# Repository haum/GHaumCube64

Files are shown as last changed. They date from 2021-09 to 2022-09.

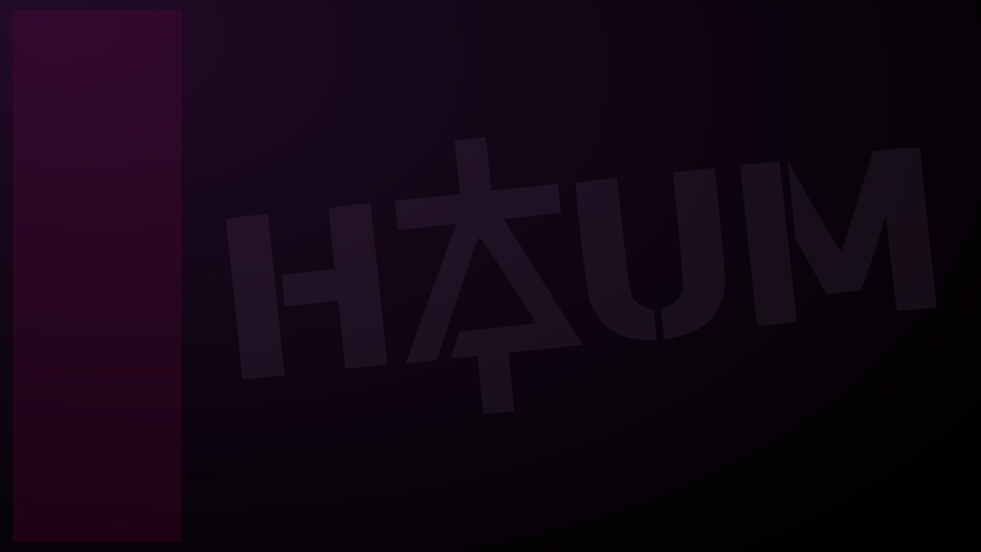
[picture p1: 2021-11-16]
code/screen_spy/bg.png

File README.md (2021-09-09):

# GHaumCube64

Le GHaumCube64 est un jeu lumineux tridimentionnel sous forme de cube suspendu dans les airs.

État du projet : En cours

## Description générale

À l'heure actuelle, le projet est définit comme étant un cube de 64 (4×4×4) tåls (nom inventé pour désigner les éléments lumineux, munis chacun de trois leds multicolores adressables), orienté sur sa pointe et suspendu ; il y a aussi une manette de jeu à lui adjoindre. L'objectif est d'y programmer des jeux tels que morpion/snake/tron en 3D.

## Organisation des fichiers

```
<repo>
├── code
│   ├── cube <= Code du cube
│   └── remote <= Code de la télécommande/manette de jeu
│   └── Tal_test <= Code de test des LEDs
└── structure
    ├── placement
    │   ├── cube.blend <= disposition des tåls dans l'espace
    │   └── placement.scad <= disposition des tåls dans l'espace, d'un point de vue fabrication
    └── tal
        ├── tal.blend <= Modèle d'un tål complet
        ├── tal_bottom.stl.xz <= Export STL (compressé) de la partie basse
        ├── tal_top.stl.xz <= Export STL (compressé) de la partie haute
        └── Ball
            ├── support_led_Tal.FCStd <= Support LEDs FreeCAD file
            └── support_led_Tal.stl <= Export STL du support de LEDs
```

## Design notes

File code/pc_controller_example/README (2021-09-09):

A few lines of Python to test tal flower LEDs

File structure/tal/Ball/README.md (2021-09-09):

As tal flowers are hard to print we starded a version with paper ball with LED inside.
Here is a support for LED inside choosen balls

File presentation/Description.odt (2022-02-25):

GHAUMCube64

Le GHAUMCube64 est une structure interactive, suspendue au dessus du sol qui propose 64 boules lumineuses multicolores disposées pour former un cube en 3D.

Il est augmenté de plusieurs télécommandes sans fil qui permettent d’interagir avec l'affichage et de prendre le contrôle du dispositif.

Avec cette installation le HAUM (Hackerspace AU Mans) emmènera les visiteurs dans un ballet de lumière à travers de jeux et de programmes spécialement développés pour que petits et grands puissent découvrir ce projets du HAUM de façon ludique, étonnante et amusante.

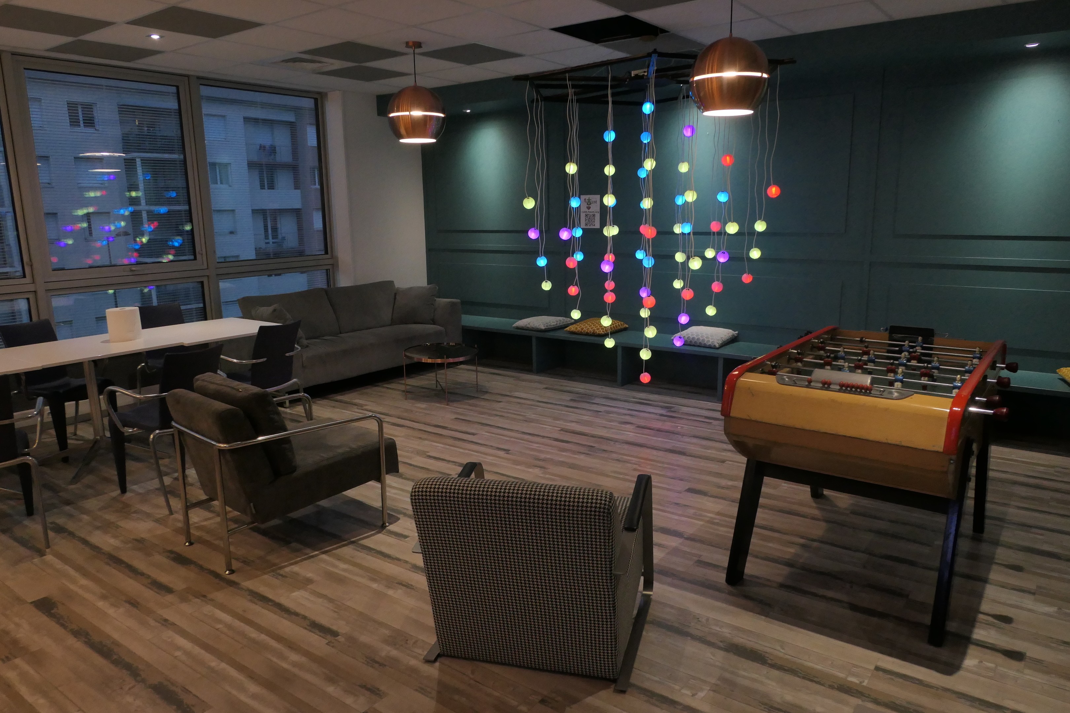
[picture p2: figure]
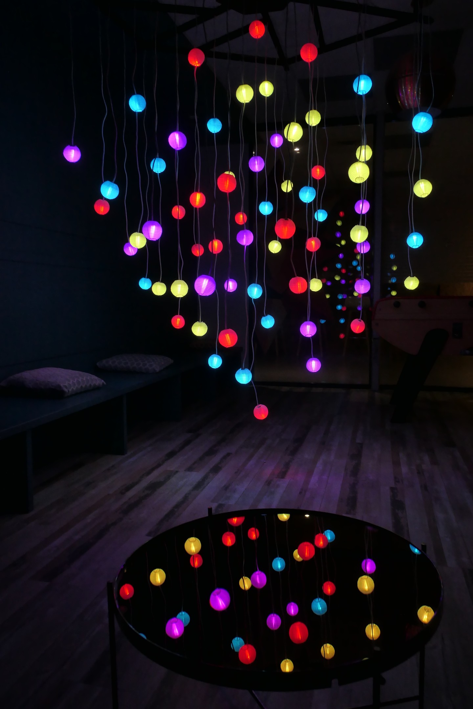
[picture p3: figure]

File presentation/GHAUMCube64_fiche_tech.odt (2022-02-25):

GHAUMCube64

Le GHAUMCube64 est une structure suspendue au-dessus du sol qui propose 64 boules lumineuses multicolores disposées pour former un cube en 3D.

Fiche technique :

installation : En intérieur

besoin électrique : Alimentation 16A qui arrive par le haut.

emprise au sol : Espace plat d’un minimum de 3m par 3m, si possible prévoir un espace libre devant pour que les spectateurs puissent appréhender la structure dans son ensemble.

Hauteur sous plafond : La structure peut être mise en œuvre dans une pièce avec une hauteur de plafond standard (2 m 60) grâce a son support autoportant. Pour une meilleure expérience il est préférable de pouvoir l’installer a une hauteur de 3m/3m50, soit grâce a son support, soit sur un point de fixation haut disponible dans la pièce l’accueillant.

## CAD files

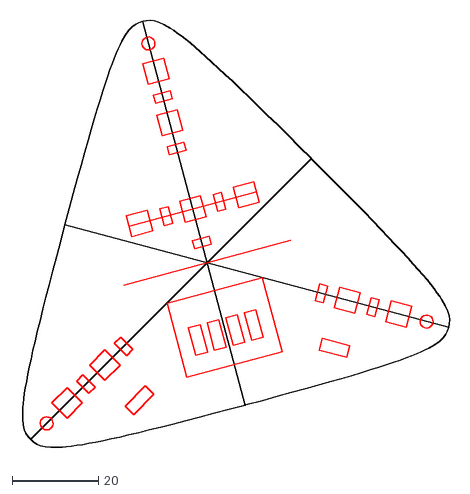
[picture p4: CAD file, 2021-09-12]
remote_board/kicad/outline_spots.dxf
101.5 x 101.5

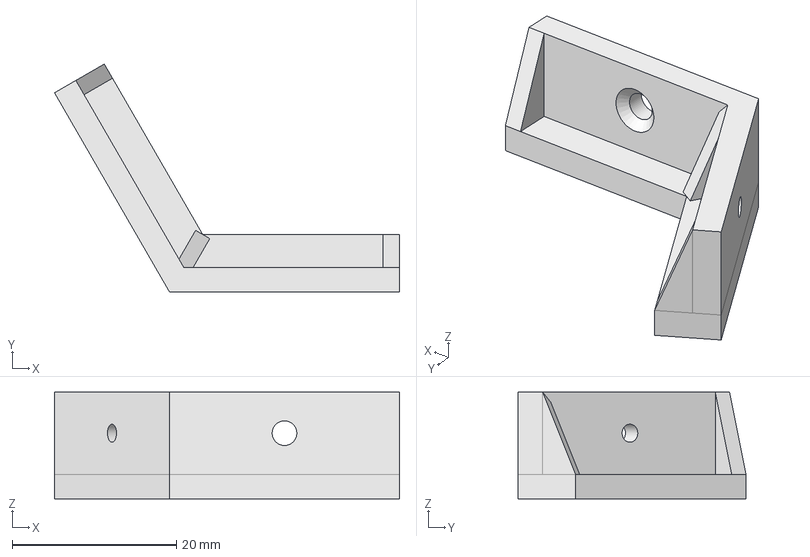
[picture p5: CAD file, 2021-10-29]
structure/placement/Doc_fabrication/connecteur_branches.FCStd
42.0 x 27.7 x 13.0 mm

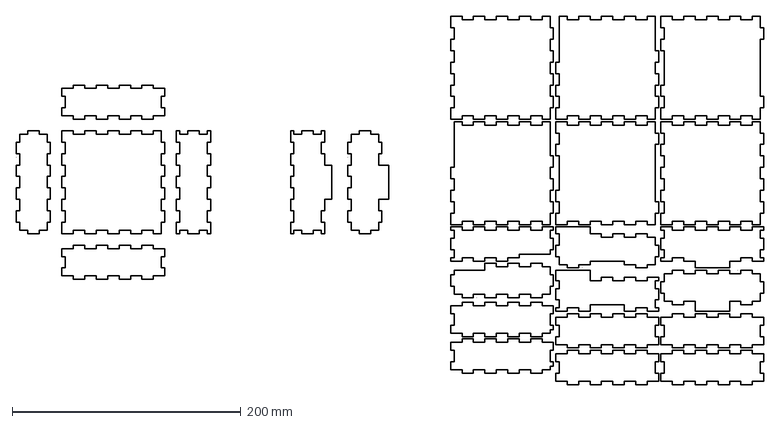
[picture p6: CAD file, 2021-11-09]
structure/placement/maquette_position_Tal.dxf
654.0 x 322.0 mm

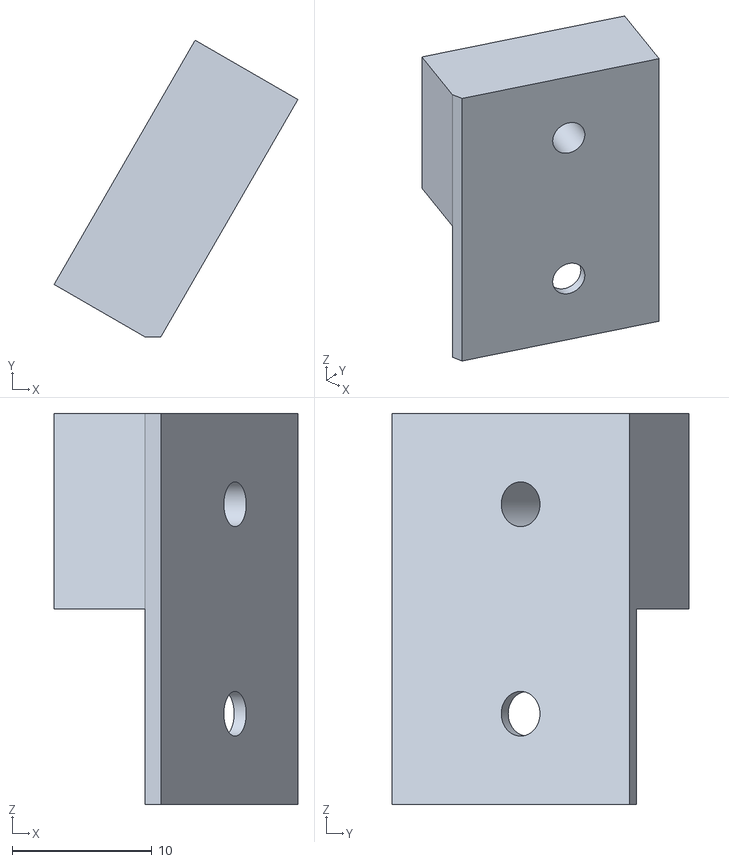
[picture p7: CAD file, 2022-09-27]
structure/raccord-support_charniere2.stl
17.5 x 21.2 x 28.0

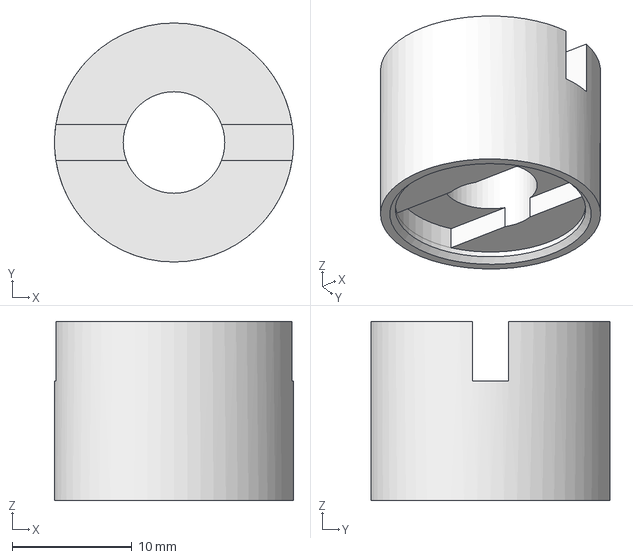
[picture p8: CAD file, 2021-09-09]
structure/tal/Ball/support_led_Tal.FCStd
20.0 x 20.0 x 15.0 mm

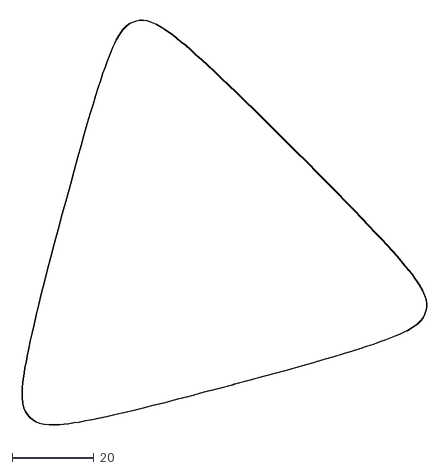
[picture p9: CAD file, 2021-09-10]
remote_board/kicad/outline.dxf
101.5 x 101.5

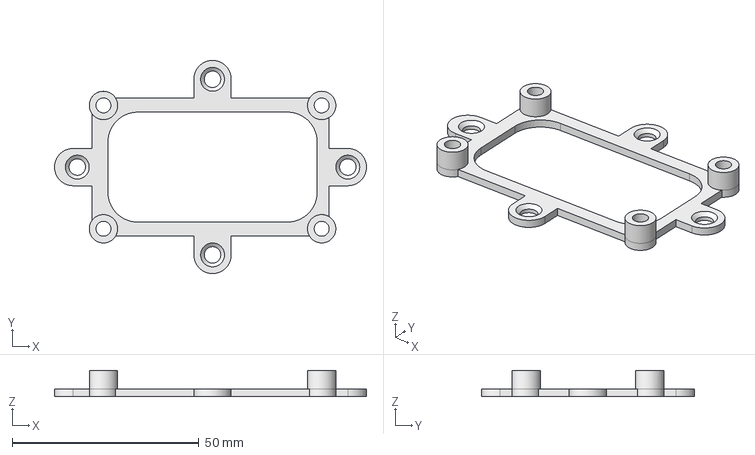
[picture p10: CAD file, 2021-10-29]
structure/placement/Doc_fabrication/support_Carte_ESP.FCStd
83.5 x 57.1 x 7.00 mm

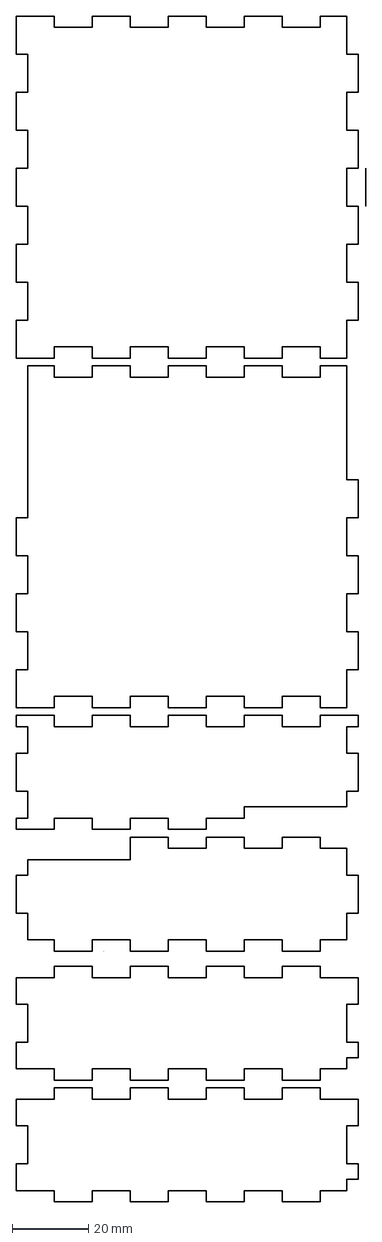
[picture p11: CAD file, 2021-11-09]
structure/placement/maquette_position_Tal1.dxf
92.0 x 312.0 mm

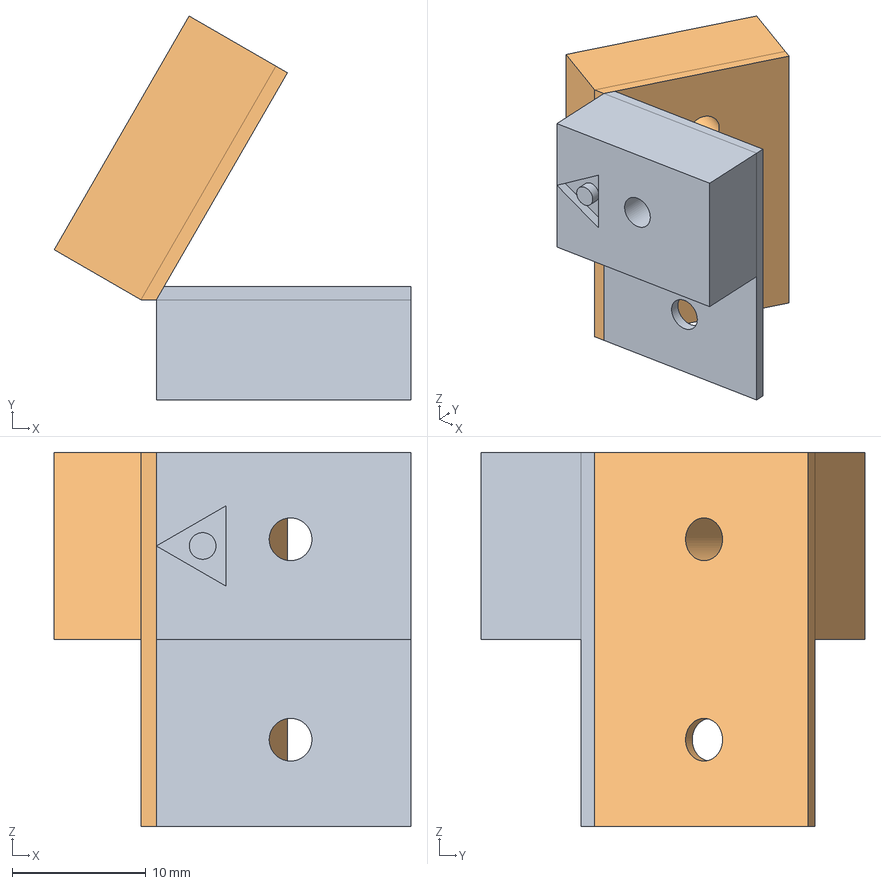
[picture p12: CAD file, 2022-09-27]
structure/raccord.FCStd
26.7 x 28.7 x 28.0 mm
support_charniere1
support_charniere2

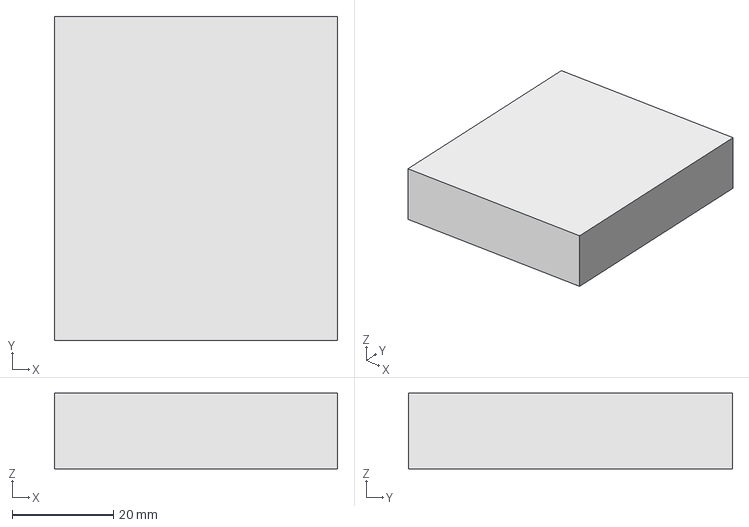
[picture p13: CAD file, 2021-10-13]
structure/placement/Doc_fabrication/centre.FCStd
56.0 x 64.0 x 15.0 mm

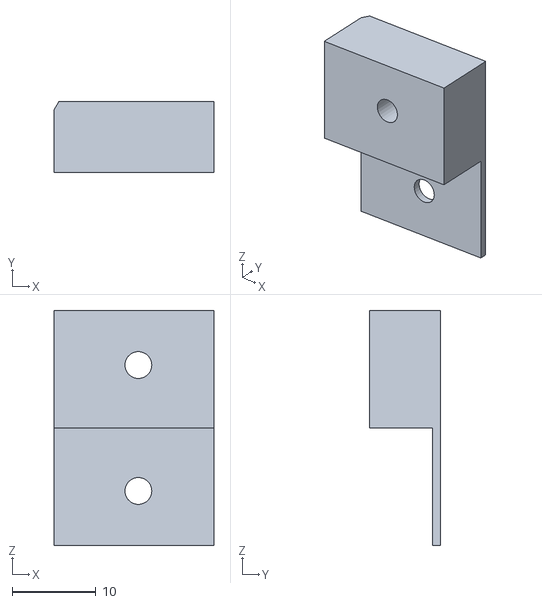
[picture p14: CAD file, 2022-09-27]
structure/raccord-support_charniere1.stl
19.0 x 8.50 x 28.0

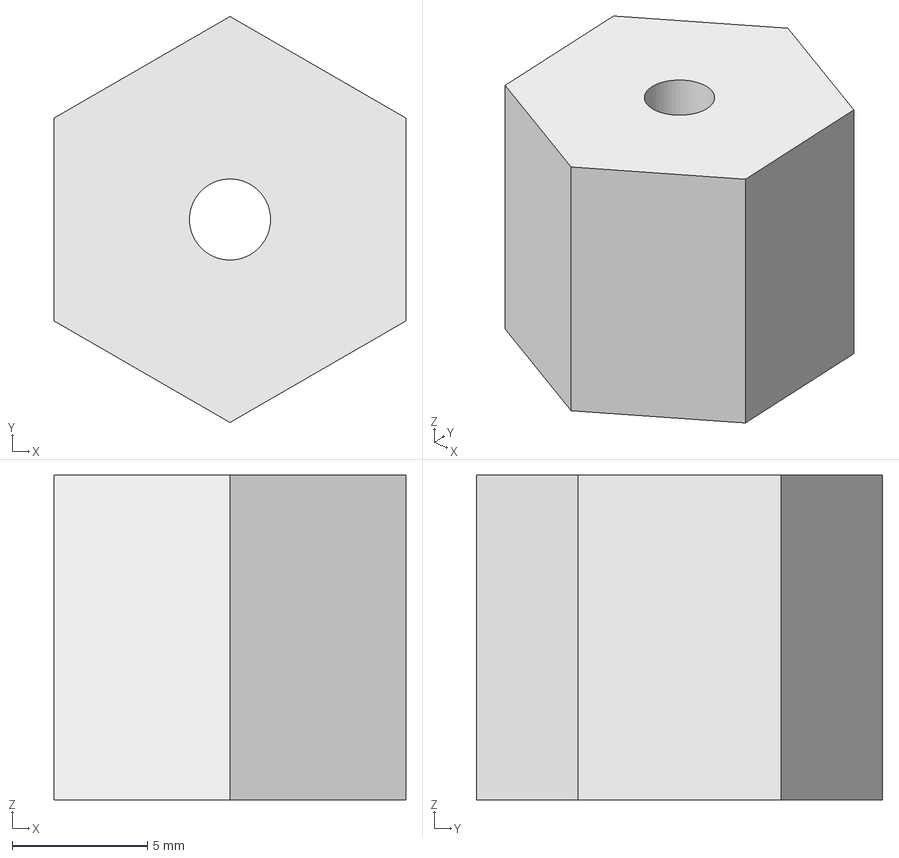
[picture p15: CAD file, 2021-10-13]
structure/placement/Doc_fabrication/Support_Alim.FCStd
13.0 x 15.0 x 12.0 mm

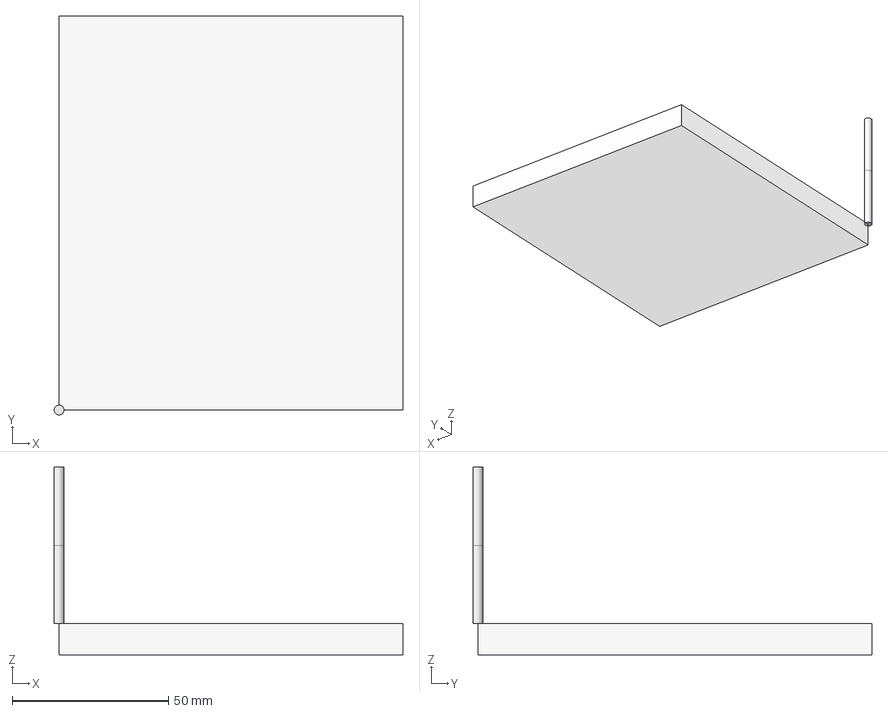
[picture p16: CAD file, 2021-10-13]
structure/placement/Doc_fabrication/support_central.FCStd
111.5 x 127.6 x 60.0 mm
Model-Body
Stock
2mm_wood
3_17mm-std

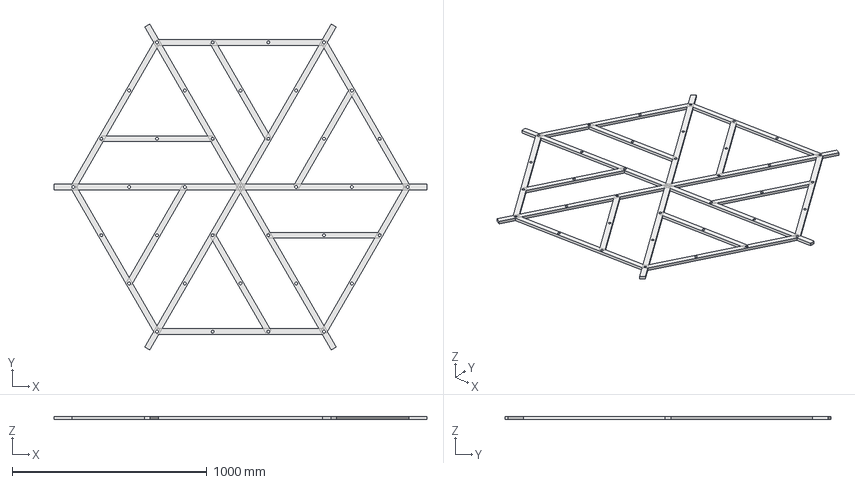
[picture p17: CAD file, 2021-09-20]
structure/placement/Doc_fabrication/Doc_fabrication.FCStd
1916.0 x 1674.3 x 15.0 mm

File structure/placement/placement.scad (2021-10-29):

/****************************************************************
** Distance entre deux tåls (sur l'arrête) : 35cm              **
** Distance entre deux tåls (sur leur fil) : √3 × 35cm ≃ 60 cm **
** Envergure : 171,5 ≃ 172 cm                                  **
** Distance entre deux tåls dans le plan XY: 28,6 cm           **
**                                                             **
** Distances des premiers tåls sur leur fil :                  **
** - rouges (×1)              :         14 cm                  **
** - bleus (×3)               :  34,2 ≃ 34 cm                  **
** - vert (×3) & magenta (×3) :  54,4 ≃ 54 cm                  **
** - jaunes (×6)              :  74.6 ≃ 75 cm                  **
** - cyan (×3)                :  94,8 ≃ 95 cm                  **
** - blancs :                                                  **
**   ⋅ 74.6  ≃  75 cm (×3)                                     **
**   ⋅ 94,8  ≃  95 cm (×6)                                     **
**   ⋅         115 cm (×6)                                     **
**   ⋅ 135,2 ≃ 135 cm (×3)                                     **
****************************************************************/

/** Verification **/
show_cable = true;
show_support = true;
show_color = true;
distance_cable = 600;
distance_support = 286;
sphere_size = 70;
cable_diameter = 3;
support_l = 30;
support_h = 15;

module cable(n, d) {
    // n: Number of tåls
    // d: Distance of the first tål
    h = d + (n - 1) * distance_cable;
    if (show_cable)
        translate([0, 0, -h])
            cylinder(h=h, r=cable_diameter);
    for (i = [0 : n-1]) {
        translate([0, 0, -d - distance_cable * i])
            sphere(d=sphere_size);
    }
}

module support_element() {
    translate([0,-(support_l/2),0])
        cube([3*distance_support+100,support_l,support_h]);

    translate([3*distance_support,0,0])
        rotate([0,0,120])
            translate([0,-(support_l/2),0])
                cube([3*distance_support,support_l,support_h]);

    translate([distance_support,0,0])
        rotate([0,0,60])
            translate([0,-(support_l/2),0])
                cube([2*distance_support,support_l,support_h]);
}

color(show_color ? "red" : "grey")
    cable(4, 140);

color(show_color ? "green" : "grey")
    for (i = [0:2]) {
        rotate([0, 0, 120*i])
        translate([distance_support, 0, 0])
            cable(3, 540);
    }

color(show_color ? "blue" : "grey")
    for (i = [0:2]) {
        rotate([0, 0, 120*i+60])
        translate([distance_support, 0, 0])
            cable(3, 340);
    }

color(show_color ? "cyan" : "grey")
    for (i = [0:2]) {
        rotate([0, 0, 120*i])
        translate([distance_support*2, 0, 0])
            cable(2, 950);
    }

color(show_color ? "magenta" : "grey")
    for (i = [0:2]) {
        rotate([0, 0, 120*i+60])
        translate([distance_support*2, 0, 0])
            cable(2, 540);
    }

color(show_color ? "yellow" : "grey")
    for (i = [0:5]) {
        rotate([0, 0, 60*i+30])
        translate([distance_support * sqrt(3), 0, 0])
            cable(2, 750);
    }

wd = [1350, 1150, 950, 750, 950, 1150];
color(show_color ? "white" : "grey")
    for (i = [0:2]) {
        for (d = [0:5]) {
           rotate([0, 0, i * 120 + d * 20])
              translate([distance_support * (d % 3 == 0 ? 3 : sqrt(7)), 0, 0])
                cable(1, wd[d]);
        }
    }

if (show_support)
    for (i = [0:5]) {
        rotate([0, 0, i * 60])
            color("black")
                support_element();
    }

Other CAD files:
structure/placement/Doc_fabrication/Centre_Support-Dessus.dxf
structure/placement/Doc_fabrication/Centre_Support.FCStd
structure/placement/Doc_fabrication/Centre_Support-Dessous.dxf
structure/placement/cube.blend
structure/raccord.stl
structure/tal/Ball/support_led_Tal.stl
structure/tal/tal.blend

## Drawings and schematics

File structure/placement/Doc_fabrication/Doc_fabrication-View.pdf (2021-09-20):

958,00

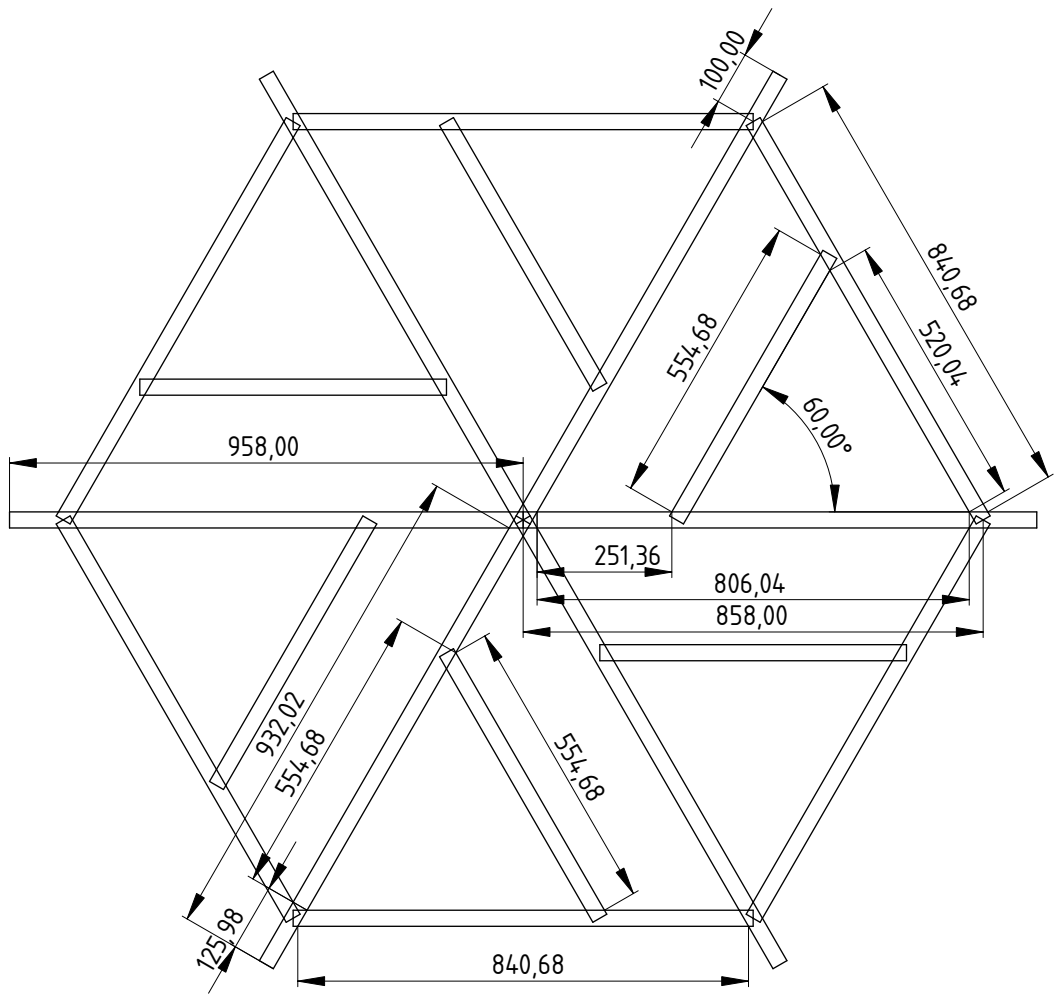
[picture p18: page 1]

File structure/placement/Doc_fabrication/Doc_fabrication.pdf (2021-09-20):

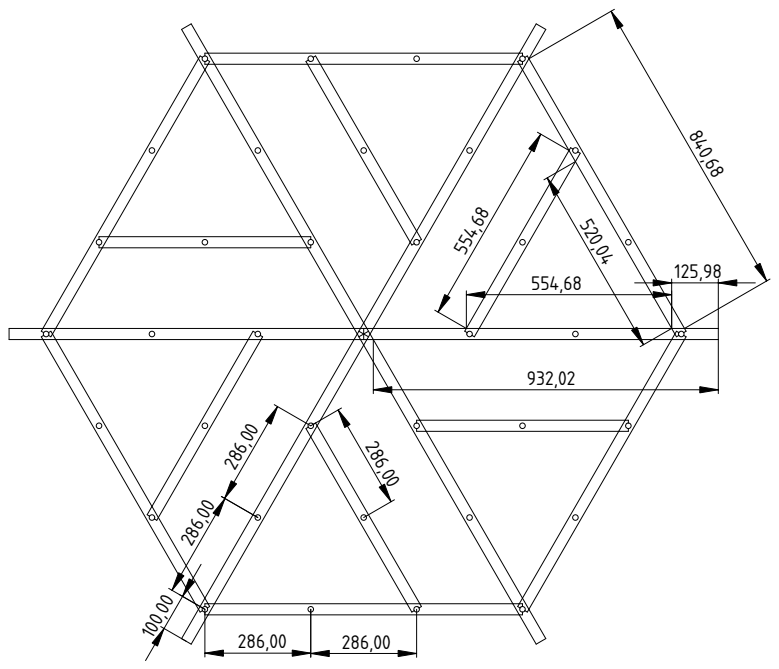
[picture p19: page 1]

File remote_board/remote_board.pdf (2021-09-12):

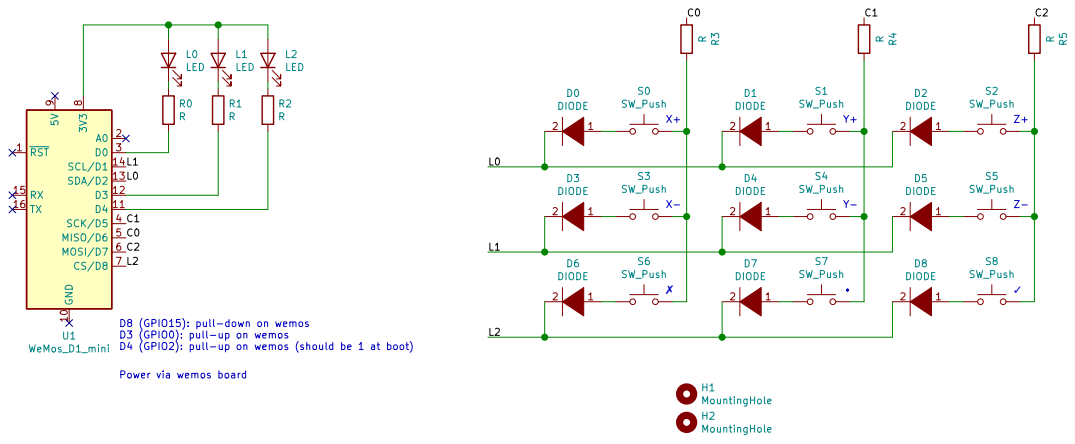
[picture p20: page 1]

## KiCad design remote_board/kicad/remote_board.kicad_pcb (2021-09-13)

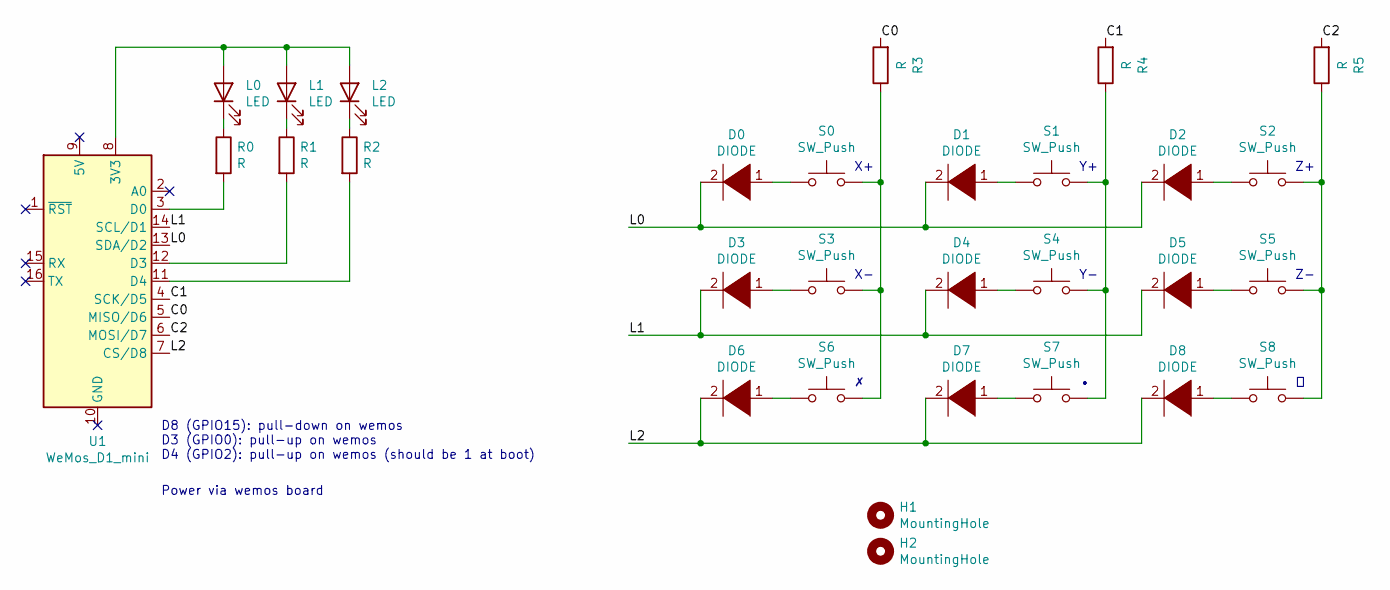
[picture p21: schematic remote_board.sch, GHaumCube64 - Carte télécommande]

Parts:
D0, D1, D2, D3, D4, D5, D6, D7, D8: DIODE; D_DO-35_SOD27_P10.16mm_Horizontal
H1, H2: MountingHole; MountingHole_5.3mm_M5
L0, L1, L2: LED; LED_D3.0mm
R0, R1, R2, R3, R4, R5: R; R_Axial_DIN0207_L6.3mm_D2.5mm_P15.24mm_Horizontal
S0, S1, S2, S3, S4, S5, S6, S7, S8: SW_Push; SW_PUSH_5mm_2pins
U1: WeMos_D1_mini; WEMOS_D1_mini_light

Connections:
/C0: R3.2, U1.5 (MISO/D6)
/C1: R4.2, U1.4 (SCK/D5)
/C2: R5.2, U1.6 (MOSI/D7)
/L0: D0.2 (A), D1.2 (A), D2.2 (A), U1.13 (SDA/D2)
/L1: D3.2 (A), D4.2 (A), D5.2 (A), U1.14 (SCL/D1)
/L2: D6.2 (A), D7.2 (A), D8.2 (A), U1.7 (CS/D8)
unnamed: D0.1 (K), S0.1
unnamed: D1.1 (K), S1.1
unnamed: D2.1 (K), S2.1
unnamed: D3.1 (K), S3.1
unnamed: D4.1 (K), S4.1
unnamed: D5.1 (K), S5.1
unnamed: D6.1 (K), S6.1
unnamed: D7.1 (K), S7.1
unnamed: D8.1 (K), S8.1
unnamed: L0.1 (K), R0.1
unnamed: L0.2 (A), L1.2 (A), L2.2 (A), U1.8 (3V3)
unnamed: L1.1 (K), R1.1
unnamed: L2.1 (K), R2.1
unnamed: R0.2, U1.3 (D0)
unnamed: R1.2, U1.12 (D3)
unnamed: R2.2, U1.11 (D4)
unnamed: R3.1, S0.2, S3.2, S6.2
unnamed: R4.1, S1.2, S4.2, S7.2
unnamed: R5.1, S2.2, S5.2, S8.2

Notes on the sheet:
D8 (GPIO15): pull-down on wemos D3 (GPIO0): pull-up on wemos D4 (GPIO2): pull-up on wemos (should be 1 at boot)
Power via wemos board

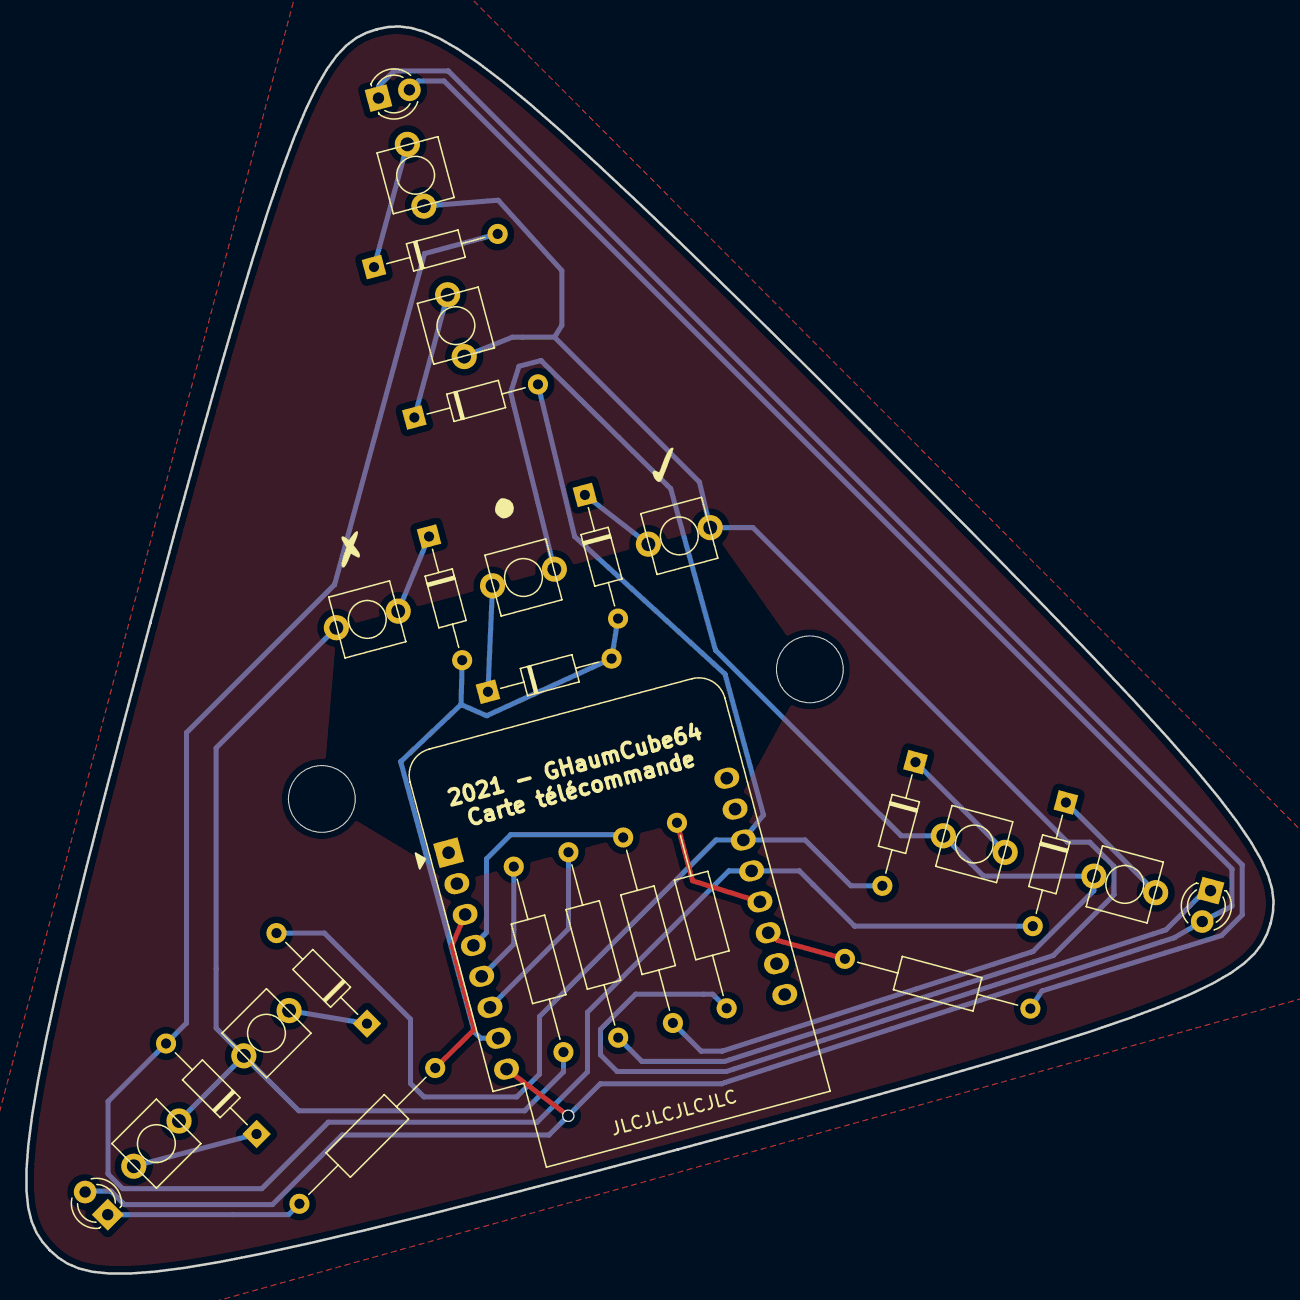
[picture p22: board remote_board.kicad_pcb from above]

Board: 2 copper layers, 99.0 x 99.0 mm, 30 parts (0 on the bottom side), 25 nets.

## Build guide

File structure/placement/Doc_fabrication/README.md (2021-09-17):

Documents relatifs a la fabrication de la structure

├── centre.FCStd <= modele du centre du support
├── Centre_Support-Dessous.dxf <= dessous du centre du support
├── Centre_Support-Dessus.dxf <= dessus du centre du support
├── Centre_Support.FCStd <= modele du support
├── Doc_fabrication.FCStd <= modele de l'ensemble de la structure
├── Doc_fabrication-View.pdf <= plan coté des support de tal
└── README.md <= ce fichier

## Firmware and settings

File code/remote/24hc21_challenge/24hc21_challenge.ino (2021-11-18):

#include <ESP8266WebServer.h>
#include <ESP8266mDNS.h>
#include <DNSServer.h>

#include "AppConfig.h"
#include "AppHttp.h"
#include "ota_helpers.h"

AppConfig config;
ESP8266WebServer webserver(80);
WiFiServer tcpbtns_server(540);
WiFiClient tcpbtns_client;
AppHttp http_handler(config, webserver);
DNSServer dns;
bool connect_enabled;
bool ap_enabled;
bool apfallback_enabled;
int led_nb = 0;

void setup() {
  pinMode(D0, OUTPUT);
  pinMode(D3, OUTPUT);
  pinMode(D4, OUTPUT);
  digitalWrite(D0, HIGH);
  digitalWrite(D3, HIGH);
  digitalWrite(D4, HIGH);

  pinMode(D2, OUTPUT);
  pinMode(D1, OUTPUT);
  pinMode(D8, OUTPUT);
  digitalWrite(D2, HIGH);
  digitalWrite(D1, HIGH);
  digitalWrite(D8, HIGH);

  pinMode(D6, INPUT_PULLUP);
  pinMode(D5, INPUT_PULLUP);
  pinMode(D7, INPUT_PULLUP);

  Serial.begin(115200);
  Serial.println("Starting 24HC21 remote control");

  config.readFromEEPROM();
  if (!strcmp(config.hostname, "")) {
    char hostString[13];
    sprintf(hostString, "GHC64_%06X", ESP.getChipId());
    config.hostname.setValue(hostString);
  }

  connect_enabled = config.connect_enabled;
  ap_enabled = config.ap_enabled;
  apfallback_enabled = config.apfallback_enabled;

  Serial.print("Hostname: ");
  Serial.println(config.hostname);

  webserver.begin();
  WiFi.hostname(config.hostname);
  if (MDNS.begin(config.hostname)){
    MDNS.addService("http", "tcp", 80);
  }
  ota_setup(config.hostname);

  Serial.print("Connection to wifi");
  if (config.connect_enabled && strcmp(config.connect_essid, "")) {
    Serial.print(": \"");
    Serial.print(config.connect_essid);
    Serial.println('"');
    WiFi.begin(config.connect_essid, config.connect_password);
  } else {
    Serial.println(" disabled");
  }
  
  Serial.print("Wifi access point");
  if (config.ap_enabled && strcmp(config.ap_essid, "")) {
    Serial.print(": \"");
    Serial.print(config.ap_essid);
    Serial.print('"');
    if (WiFi.softAP(config.ap_essid, config.ap_password)) {
      Serial.print(' ');
      Serial.println(WiFi.softAPIP());
      dns.start(53, "*", WiFi.softAPIP());
    } else {
      Serial.println(" failed");
      ap_enabled = false;
    }
  } else {
    WiFi.softAPdisconnect();
    Serial.println(" disabled");
  }

  MDNS.begin(config.hostname.value());
  tcpbtns_server.begin();
}

int buttons = 0;
int leds = -1;
bool connectionFailed = false;
int connectCounter = 0;
long next_change_led = 0;
long next_change_btns = 0;
void loop() {
  ota_loop();
  dns.processNextRequest();
  webserver.handleClient();

  if (WiFi.status() == WL_CONNECTED) {
    long time = millis();
    if (time > next_change_led) {
      next_change_led = time + 200;
      led_nb = (led_nb + 1) % 3;
      if (leds < 0 || leds > 7) {
        digitalWrite(D0, led_nb != 0);
        digitalWrite(D3, led_nb != 1);
        digitalWrite(D4, led_nb != 2);
      } else {
        digitalWrite(D0, (leds & 1) == 0);
        digitalWrite(D3, (leds & 2) == 0);
        digitalWrite(D4, (leds & 4) == 0);
      }
    }
  }

  WiFiClient client = tcpbtns_server.available();
  if (client) {
    tcpbtns_client.stop();
    tcpbtns_client = client;
    tcpbtns_client.print("24HC21 remote\r\n");
    leds = 0;
  }

  if (tcpbtns_client.available()) {
    leds = tcpbtns_client.parseInt();
    long toread = tcpbtns_client.available();
    for (int i = 0; i < toread; ++i) tcpbtns_client.read();
  }
  if (!tcpbtns_client.connected()) leds = -1;

  long time = millis();
  if (time > next_change_btns) {
    next_change_btns = time + 50;

    int old = buttons;
    buttons = 0;

    digitalWrite(D2, LOW);
    buttons |= !digitalRead(D6) ? 1 << 0 : 0;
    buttons |= !digitalRead(D5) ? 1 << 1 : 0;
    buttons |= !digitalRead(D7) ? 1 << 2 : 0;
    digitalWrite(D2, HIGH);

    digitalWrite(D1, LOW);
    buttons |= !digitalRead(D6) ? 1 << 3 : 0;
    buttons |= !digitalRead(D5) ? 1 << 4 : 0;
    buttons |= !digitalRead(D7) ? 1 << 5 : 0;
    digitalWrite(D1, HIGH);

    digitalWrite(D8, LOW);
    buttons |= !digitalRead(D6) ? 1 << 6 : 0;
    buttons |= !digitalRead(D5) ? 1 << 7 : 0;
    buttons |= !digitalRead(D7) ? 1 << 8 : 0;
    digitalWrite(D8, HIGH);

    if (old != buttons)
      tcpbtns_client.print(String(buttons, DEC)+"\r\n");
  }

  // Connection indicator
  if (connect_enabled && !connectionFailed) {
    if (WiFi.status() != WL_CONNECTED) {
      if (connectCounter == 50) {
        digitalWrite(D0, LOW);
        digitalWrite(D3, LOW);
        digitalWrite(D4, LOW);
        connectCounter++;
        WiFi.disconnect();
        Serial.println("Connection failed (too long)");
        connectionFailed = true;
      } else {
        long time = millis();
        if (time > next_change_led) {
          digitalWrite(D0, !digitalRead(D0));
          digitalWrite(D3, !digitalRead(D3));
          digitalWrite(D4, !digitalRead(D4));
          next_change_led = time + 200;
          connectCounter++;
        }
      }
    } else if (connectCounter != -1) {
      Serial.print("Wifi connected: ");
      Serial.println(WiFi.localIP());
      digitalWrite(D0, HIGH);
      digitalWrite(D3, HIGH);
      digitalWrite(D4, HIGH);
      connectCounter = -1;
    }
  } else {
    connectionFailed = true;
  }

  // Fallback
  if (connectionFailed && !ap_enabled) {
    if (apfallback_enabled) {
      Serial.print("Access point fallback enabled: \"");
      Serial.print(config.hostname);
      Serial.print('"');

      if (WiFi.softAP(config.hostname, "")) {
        Serial.print(' ');
        Serial.println(WiFi.softAPIP());
        dns.start(53, "*", WiFi.softAPIP());
        ap_enabled = true;
      } else {
        Serial.println(" failed");
        delay(3000);
        ESP.restart();
      }
    } else {
      delay(3000);
      ESP.restart();
    }
  }
}

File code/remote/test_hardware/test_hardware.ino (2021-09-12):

const int leds[] = {D0, D3, D4};
int led_nb = 0;

void setup() {
  pinMode(D0, OUTPUT);
  pinMode(D3, OUTPUT);
  pinMode(D4, OUTPUT);
  digitalWrite(D0, HIGH);
  digitalWrite(D3, HIGH);
  digitalWrite(D4, HIGH);

  pinMode(D2, OUTPUT);
  pinMode(D1, OUTPUT);
  pinMode(D8, OUTPUT);
  digitalWrite(D2, HIGH);
  digitalWrite(D1, HIGH);
  digitalWrite(D8, HIGH);

  pinMode(D6, INPUT_PULLUP);
  pinMode(D5, INPUT_PULLUP);
  pinMode(D7, INPUT_PULLUP);

  Serial.begin(115200);
}

void loop() {
  led_nb = (led_nb + 1) % 3;
  digitalWrite(D0, HIGH);
  digitalWrite(D3, HIGH);
  digitalWrite(D4, HIGH);
  digitalWrite(leds[led_nb], LOW);
  delay(200);

  digitalWrite(D2, LOW);
  if (!digitalRead(D6)) Serial.println("X+");
  if (!digitalRead(D5)) Serial.println("Y+");
  if (!digitalRead(D7)) Serial.println("Z+");
  digitalWrite(D2, HIGH);

  digitalWrite(D1, LOW);
  if (!digitalRead(D6)) Serial.println("X-");
  if (!digitalRead(D5)) Serial.println("Y-");
  if (!digitalRead(D7)) Serial.println("Z-");
  digitalWrite(D1, HIGH);

  digitalWrite(D8, LOW);
  if (!digitalRead(D6)) Serial.println("✗");
  if (!digitalRead(D5)) Serial.println("•");
  if (!digitalRead(D7)) Serial.println("✓");
  digitalWrite(D8, HIGH);
}

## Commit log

2020-06-11 Add blender model of tål
    [tal.blend]
2020-06-11 Add STL exports of tål
2020-06-11 Add visual expected 3D placement of the tåls in blender format
    [cube.blend]
2021-02-09 Update the model of tål for better printing
    [tal.blend]
2021-09-09 add LEDs support for Tal flower remplacement
    [support_led_Tal.FCStd, support_led_Tal.stl]
2021-09-09 simple code for testing LEDs
2021-09-09 Add scad to check dimentions
    [placement.scad]
2021-09-10 Add remote kicad project
    [outline.dxf, outline_spots.dxf, remote_board.kicad_pcb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]
2021-09-10 Change structure to real dimention in scad file Add fabrication doc
    [Doc_fabrication.FCStd, placement.scad]
2021-09-11 add gitignore file update fab doc
    [Doc_fabrication.FCStd]
2021-09-12 Update remote kicad schematic
    Fixes from prototype:
    - invert C1 & L2 (D8 always measures LOW level)
    - invert leds on D3/D4 (for the builtin led to be on Z)
    [remote_board.kicad_pcb, remote_board.sch]
2021-09-12 Change button footprint in remote board
    [remote_board.kicad_pcb, remote_board.sch]
2021-09-12 Change component placement in remote board
    [outline_spots.dxf, remote_board.kicad_pcb]
2021-09-12 Change meaning of left/right buttons in remote board
    [remote_board.kicad_pcb, remote_board.sch]
2021-09-12 Add sketch to test hardware of the remote board
2021-09-12 Add schematic of remote board as PDF
2021-09-12 Export gerbers for the remote board
    [remote_board-B_Cu.gbr, remote_board-B_Mask.gbr, remote_board-B_SilkS.gbr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]
2021-09-13 change in PCB design for fab needs
    [remote_board-B_Cu.gbr, remote_board-B_Mask.gbr, remote_board-B_SilkS.gbr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]
2021-09-17 More fab docs
    [Centre_Support-Dessous.dxf, Centre_Support-Dessus.dxf, Centre_Support.FCStd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]
2021-09-20 Add Tals place in model Updated docs for Fab
    [Doc_fabrication.FCStd]
2021-09-20 idea for a 3dprinted piece for assembling parts
    [connecteur_branches.FCStd]
2021-10-12 Display led after fill() function
2021-10-13 more construction doc
    [Support_Alim.FCStd, centre.FCStd, support_central.FCStd]
2021-10-19 Update placement spec to match real prototype errors
    [placement.scad]
2021-10-26 new dimention for connecteur_branches
    [connecteur_branches.FCStd]
2021-10-29 support for ESP based control board
    [support_Carte_ESP.FCStd]
2021-10-29 adjustment in connecteur_branches part
    [connecteur_branches.FCStd]
2021-11-09 maquette d'absraction pour la possition des leds
    [maquette_position_Tal.dxf, maquette_position_Tal1.dxf]
2021-11-09 Add TCP stream to get buttons and control leds for the 24hc21 challenge
2021-11-11 Remove obsolete Led_test test
2021-11-16 Make screen_spy react to USR1 signal with statistics print
2021-11-17 control sending thread before closing software
2021-11-18 Avoid println in 24hc21_challenge, because it sends two packets
    [24hc21_challenge.ino]
2022-02-25 Document de présentation du GHAUMCube64
2022-08-26 Add cut drawing for protective back of the remote board
2022-09-07 raccord de contruction pour une structure pliable
    [raccord.FCStd]
2022-09-07 suite raccord
    [raccord.FCStd]
2022-09-13 stl du raccord
    [raccord.stl]
2022-09-27 support charniere
    [raccord-support_charniere1.stl, raccord-support_charniere2.stl, raccord.FCStd]
